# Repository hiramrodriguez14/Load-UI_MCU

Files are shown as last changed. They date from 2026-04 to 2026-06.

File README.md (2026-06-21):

# Horizontal Axis Wind Turbine Electronic Control Unit (ECU)

## Load Control & User Interface PCB

Printed Circuit Board (PCB) design for the **Load Control & User Interface (Load & UI) MCU** of the **Horizontal Axis Wind Turbine Electronic Control Unit (ECU)**.

This repository contains the complete KiCad hardware design, manufacturing files, and production documentation for the embedded controller responsible for battery charging, power management, user interaction, and system monitoring.

---

# Documentation & Demo

| Resource | Link |
| --- | --- |
| 🎥 Project Demonstration | https://www.youtube.com/watch?v=vS5Ok38P1Jk |
| 📄 Final Project Report | https://drive.google.com/file/d/1cckKhvj7mvzCEbm3IqWp0KvrUp9g6mgg/view?usp=sharing |
| 📚 Technical Appendix | https://drive.google.com/file/d/1xu7MtcffDlpna8_BUkwEc_BfjpQJpUep/view?usp=sharing |

---

# Overview

The Load Control & User Interface PCB serves as the primary electrical control board of the Horizontal Axis Wind Turbine Electronic Control Unit (ECU).

Designed using **KiCad**, this board integrates sensing, power management, user interaction, communication, and data logging into a single embedded platform. It operates alongside the Turbine MCU PCB to provide complete supervision of the wind turbine system.

The PCB was designed with debugging, manufacturability, and future expansion in mind, incorporating dedicated test points, modular circuitry, and production-ready manufacturing files.

---

# Engineering Highlights

- Custom 2-layer PCB
- Designed in KiCad
- Texas Instruments MSPM0G3519
- Dual INA229 Power Monitors
- SEPIC Converter Control
- Battery Management System (BMS)
- LCD User Interface
- Push Button Interface
- Status LEDs
- UART Communication
- microSD Card Interface
- Relay Driver
- Barrel Jack Power Input
- Production-ready Gerber files
- Pick-and-Place (CPL) files
- Manufacturing BOM

---

# Hardware Features

The PCB integrates the following subsystems:

### Power Management

- Battery charging controller
- SEPIC converter interface
- Power monitoring
- Relay control
- Load protection

### User Interface

- 20×4 LCD connector
- Navigation buttons
- Record button
- Start / Stop controls
- Status LEDs

### Communication

- UART interface to Turbine MCU
- Programming interface
- Debug connectors

### Data Logging

- microSD card socket
- Real-Time Clock (RTC)

---

# Hardware Architecture

The Load Control & UI PCB serves as the electrical management hub of the complete ECU.

Primary functions include:

- Battery charging
- Converter control
- Power measurement
- User interaction
- Data logging
- Load protection
- Communication with the Turbine MCU

<p align="center">
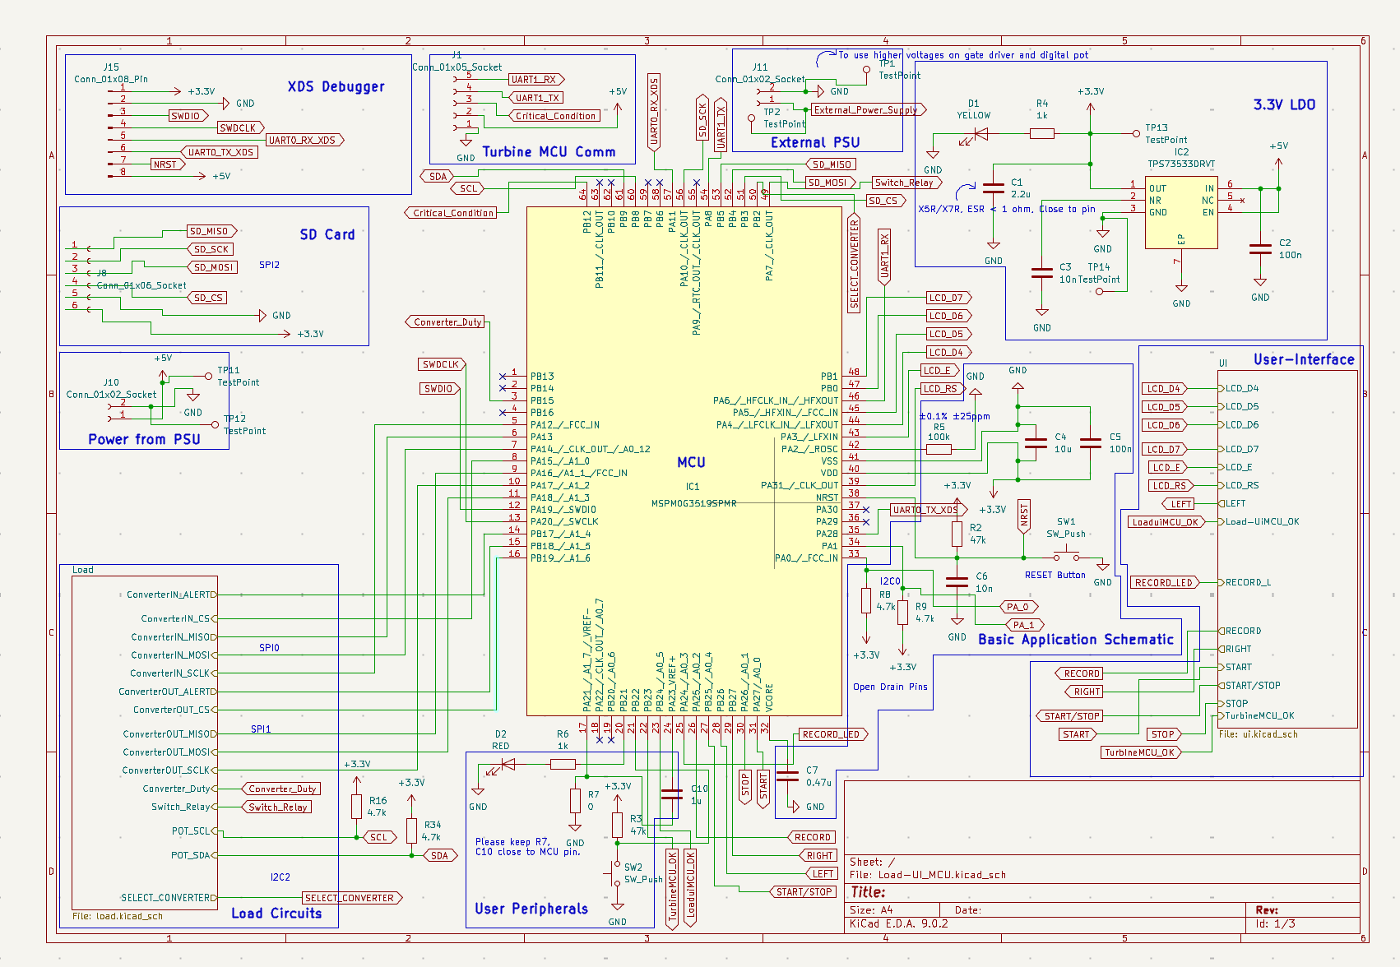
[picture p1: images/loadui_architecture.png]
  
</p>

<p align="center">
<b>Figure 1.</b> Load & UI MCU Architecture
</p>

---

# PCB Design

The board was designed using KiCad following standard PCB design practices for embedded systems.

Design considerations include:

- Component placement optimization
- Short signal routing
- Power integrity
- Ground plane utilization
- Test point accessibility
- Manufacturing compatibility

## Top Layer

<p align="center">
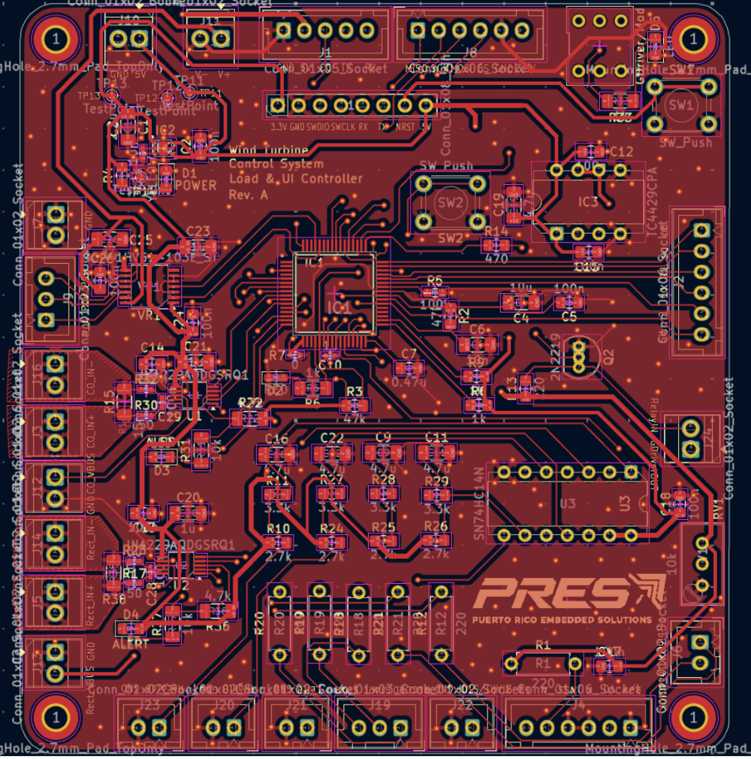
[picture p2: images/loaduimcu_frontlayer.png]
  
</p>

<p align="center">
<b>Figure 2.</b> Top Layer PCB Layout
</p>

---

## Bottom Layer

<p align="center">
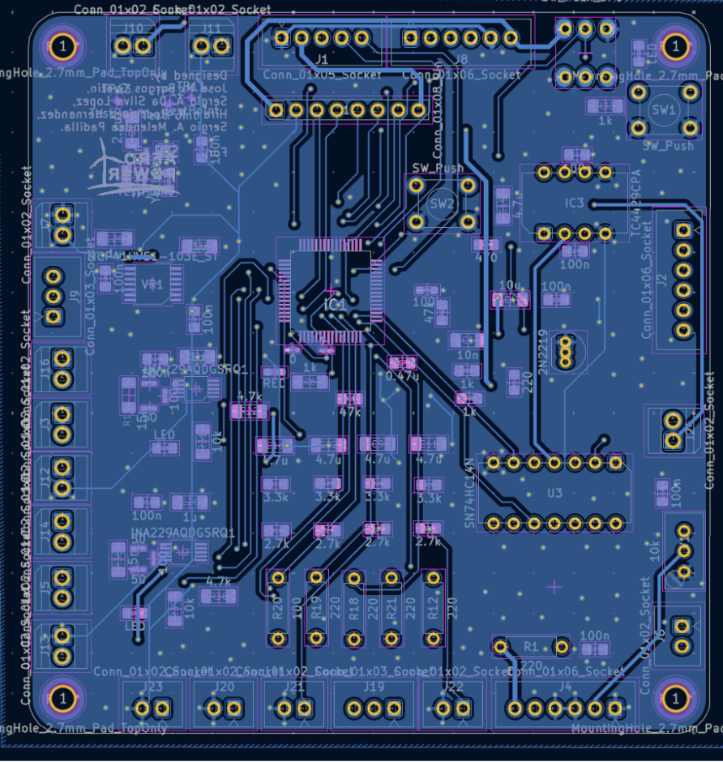
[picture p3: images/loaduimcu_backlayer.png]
  
</p>

<p align="center">
<b>Figure 3.</b> Bottom Layer PCB Layout
</p>

---

## Combined Layer View

<p align="center">
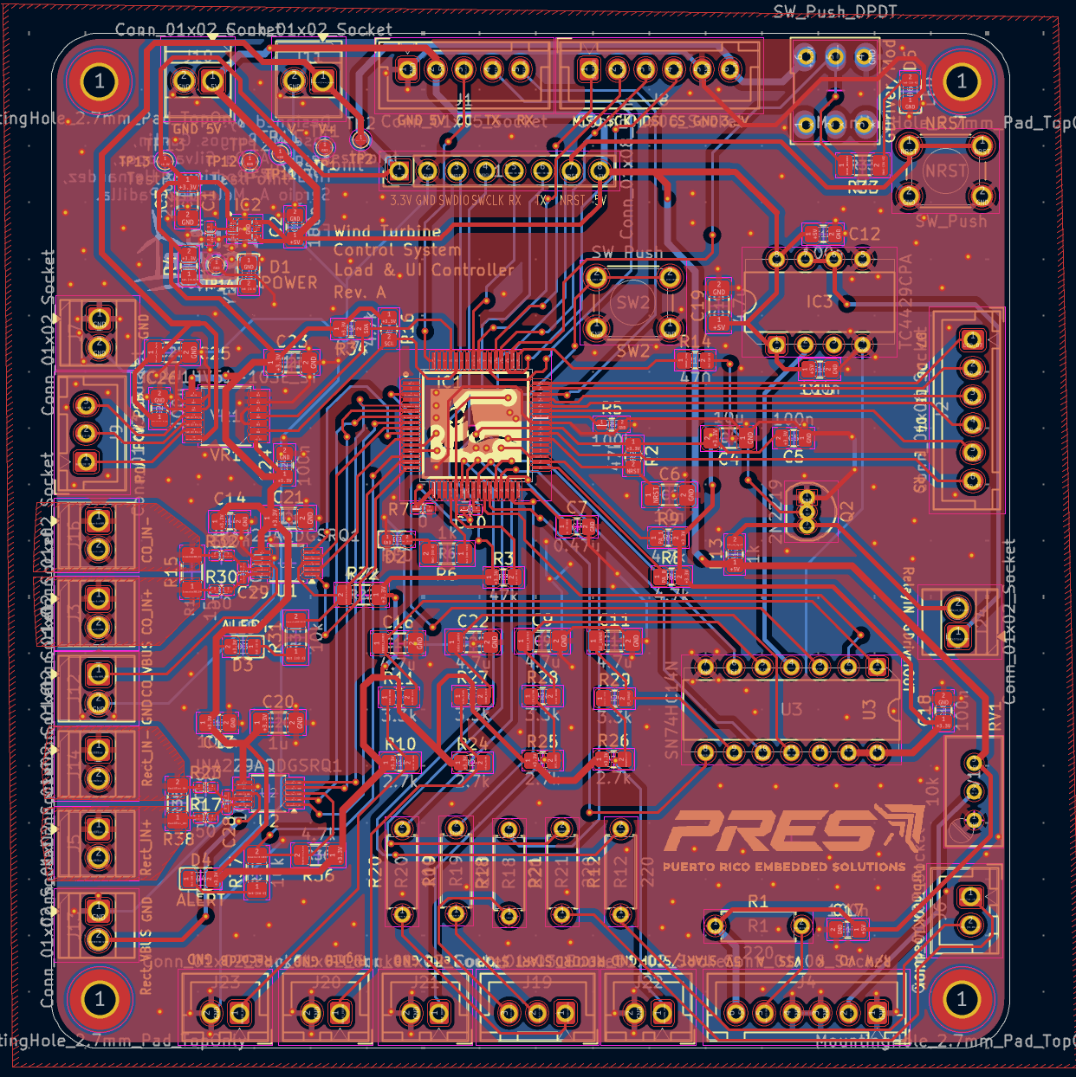
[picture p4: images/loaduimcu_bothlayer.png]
  
</p>

<p align="center">
<b>Figure 4.</b> Combined PCB Layers
</p>

---

## 3D PCB View

<p align="center">
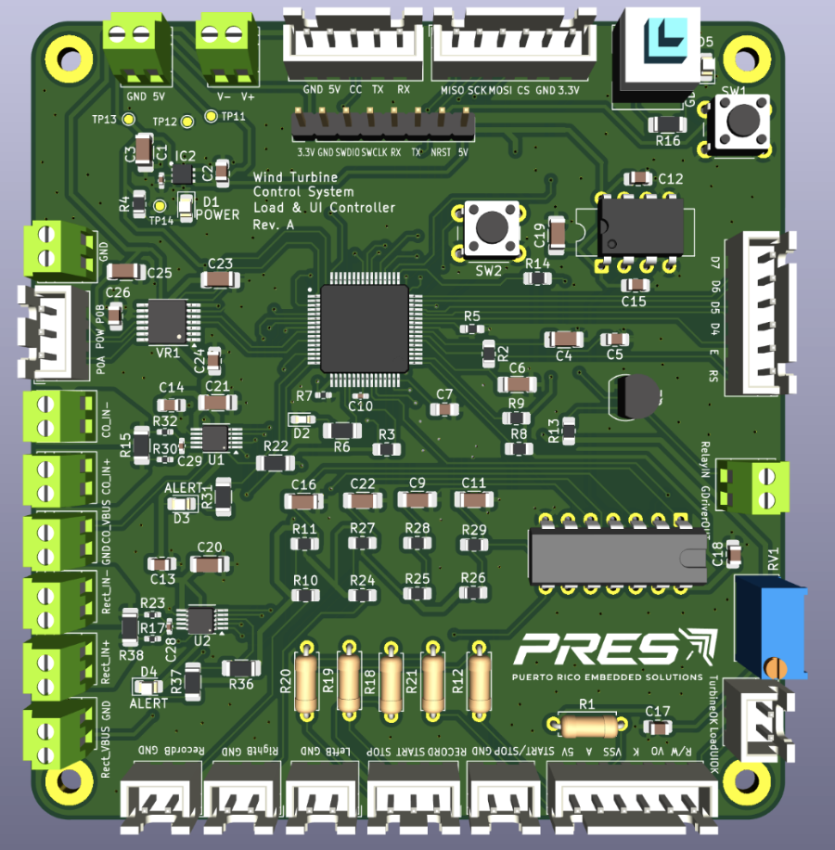
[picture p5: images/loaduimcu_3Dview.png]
  
</p>

<p align="center">
<b>Figure 5.</b> 3D PCB Rendering
</p>

---

# Manufacturing Files

This repository includes all files required for PCB fabrication and assembly.

Included manufacturing assets:

- Gerber files
- Drill files
- Pick-and-Place (CPL)
- Bill of Materials (BOM)
- Complete schematic
- PCB layout

---

# Development Tools

## PCB Design

- KiCad

## Target MCU

- Texas Instruments MSPM0G3519

---

# Repository Structure

```text
HAWT-LoadUI-PCB
│
├── gerbers/                    Manufacturing Gerber files
├── images/                     Documentation images
├── mylib/                      Custom KiCad component library
├── Load-UI_MCU.kicad_pcb       PCB layout
├── Load-UI_MCU.kicad_sch       Main schematic
├── Load-UI_MCU.kicad_pro       KiCad project
├── Load-UI_MCU-final.csv       Manufacturing BOM
├── Load-UI_MCU-all-pos.csv     Pick-and-Place (CPL)
├── load.kicad_sch              Power subsystem schematic
├── ui.kicad_sch                User Interface schematic
├── README.md                   Repository documentation
└── LICENSE                     Project license
```

---

# Related Repositories

| Repository | Description |
| --- | --- |
| HAWT-TurbineMCU-Firmware | Turbine control firmware |
| HAWT-Load_Control_and_UI | Load Control & UI firmware |
| Turbine_MCU | Turbine MCU PCB |

---

# Authors

- Hiram R. Rodríguez Hernández
- José M. Burgos Guntín
- Sergio A. Meléndez Padilla
- Sergio A. Da Silva López

Department of Electrical & Computer Engineering

University of Puerto Rico – Mayagüez

---

# License

This project was developed for educational and research purposes as part of the Embedded Systems Design course at the University of Puerto Rico – Mayagüez.

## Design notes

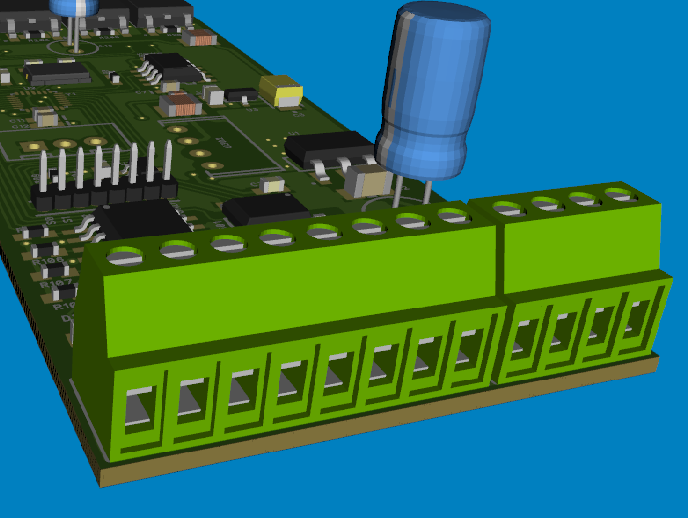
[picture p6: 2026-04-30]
mylib/kf128-screw-terminal-2-54-mm-pitch-1.snapshot.2/KF128-2.54-xx.png

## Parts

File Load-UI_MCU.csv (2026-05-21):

Designator | Qty | Comment | DNP | Exclude from BOM | Exclude from Board | Footprint | Datasheet | JLCPCB Part#
C1 | 1 | 2.2u |  |  |  | Capacitor_SMD:C_1206_3216Metric_Pad1.33x1.80mm_HandSolder | ~ | C50254
C2,C5,C12,C13,C14,C15,C17,C18,C24,C26 | 10 | 100n |  |  |  | Capacitor_SMD:C_0805_2012Metric_Pad1.18x1.45mm_HandSolder | ~ | C28233
C3 | 1 | 10n |  |  |  | Capacitor_SMD:C_0402_1005Metric_Pad0.74x0.62mm_HandSolder | ~ | C15195
C4 | 1 | 10u |  |  |  | Capacitor_SMD:C_1206_3216Metric_Pad1.33x1.80mm_HandSolder | ~ | C13585
C6 | 1 | 10n |  |  |  | Capacitor_SMD:C_1206_3216Metric_Pad1.33x1.80mm_HandSolder | ~ | C1846
C7 | 1 | 0.47u |  |  |  | Capacitor_SMD:C_0805_2012Metric_Pad1.18x1.45mm_HandSolder | ~ | C13967
C9,C11,C16,C19,C22 | 5 | 4.7u |  |  |  | Capacitor_SMD:C_1206_3216Metric_Pad1.33x1.80mm_HandSolder | ~ | C29823
C10 | 1 | 1u |  |  |  | Capacitor_SMD:C_0402_1005Metric_Pad0.74x0.62mm_HandSolder | ~ | C52923
C20,C21,C23,C25 | 4 | 1u |  |  |  | Capacitor_SMD:C_1206_3216Metric_Pad1.33x1.80mm_HandSolder | ~ | C1848
C28,C29 | 2 | 100n |  |  |  | Capacitor_SMD:C_0402_1005Metric_Pad0.74x0.62mm_HandSolder | ~ | C307331
D1 | 1 | YELLOW |  |  |  | LED_SMD:LED_0805_2012Metric_Pad1.15x1.40mm_HandSolder | ~ | C2296
D2 | 1 | RED |  |  |  | LED_SMD:LED_0603_1608Metric_Pad1.05x0.95mm_HandSolder | ~ | C2286
D3,D4,D6 | 3 | LED |  |  |  | LED_SMD:LED_0805_2012Metric_Pad1.15x1.40mm_HandSolder | ~ | C2296
IC1 | 1 | MSPM0G3519SPMR |  |  |  | MSPM0SPMR:QFP50P1200X1200X160-64N | https://www.ti.com/lit/ds/symlink/mspm0g3505.pdf?ts=1706855132968 | C49259417
IC2 | 1 | TPS73533DRVT |  |  |  | TPS73533DRVT:SON65P200X200X80-7N | http://www.ti.com/lit/ds/symlink/tps735.pdf | C48984
IC3 | 1 | TC4429CPA |  |  | YES | Package_DIP:CERDIP-8_W7.62mm_SideBrazed | https://ww1.microchip.com/downloads/en/DeviceDoc/21419D.pdf
J1 | 1 | Conn_01x05_Socket |  |  | YES | Connector_JST:JST_XH_B5B-XH-A_1x05_P2.50mm_Vertical | ~
J2,J4,J8 | 3 | Conn_01x06_Socket |  |  | YES | Connector_JST:JST_XH_B6B-XH-A_1x06_P2.50mm_Vertical | ~
J3,J5,J7,J10,J11,J12,J13,J14,J16,J24 | 10 | Conn_01x02_Socket |  |  | YES | TerminalBlock:TerminalBlock_Xinya_XY308-2.54-2P_1x02_P2.54mm_Horizontal | ~
J6,J20,J21,J22,J23 | 5 | Conn_01x02_Socket |  |  | YES | Connector_JST:JST_XH_B2B-XH-A_1x02_P2.50mm_Vertical | ~
J9,J19 | 2 | Conn_01x03_Socket |  |  | YES | Connector_JST:JST_XH_B3B-XH-A_1x03_P2.50mm_Vertical | ~
J15 | 1 | Conn_01x08_Pin |  |  | YES | Connector_PinHeader_2.54mm:PinHeader_1x08_P2.54mm_Vertical | ~
Q2 | 1 | 2N2219 |  |  | YES | Package_TO_SOT_THT:TO-92_Inline | http://www.onsemi.com/pub_link/Collateral/2N2219-D.PDF
R1,R12,R18,R19,R21 | 5 | 220 |  |  | YES | Resistor_THT:R_Axial_DIN0207_L6.3mm_D2.5mm_P7.62mm_Horizontal | ~
R2,R3 | 2 | 47k |  |  |  | Resistor_SMD:R_0805_2012Metric_Pad1.20x1.40mm_HandSolder | ~ | C17713
R4,R13 | 2 | 1k |  |  |  | Resistor_SMD:R_0805_2012Metric_Pad1.20x1.40mm_HandSolder | ~ | C17513
R5 | 1 | 100k |  |  |  | Resistor_SMD:R_0603_1608Metric_Pad0.98x0.95mm_HandSolder | ~ | C25803
R6,R33 | 2 | 1k |  |  |  | Resistor_SMD:R_1206_3216Metric_Pad1.30x1.75mm_HandSolder | ~ | C4410
R7 | 1 | 0R |  |  |  | Resistor_SMD:R_0402_1005Metric_Pad0.72x0.64mm_HandSolder | ~ | C17168
R8,R9,R16,R34 | 4 | 4.7k |  |  |  | Resistor_SMD:R_0805_2012Metric_Pad1.20x1.40mm_HandSolder | ~ | C17675
R10,R24,R25,R26 | 4 | 2.7k |  |  |  | Resistor_SMD:R_0805_2012Metric_Pad1.20x1.40mm_HandSolder | ~ | C17530
R11,R27,R28,R29 | 4 | 3.3k |  |  |  | Resistor_SMD:R_0805_2012Metric_Pad1.20x1.40mm_HandSolder | ~ | C26010
R14 | 1 | 470 |  |  |  | Resistor_SMD:R_0805_2012Metric_Pad1.20x1.40mm_HandSolder | ~ | C17710
R15,R38 | 2 | 15m |  |  |  | Resistor_SMD:R_1206_3216Metric_Pad1.30x1.75mm_HandSolder | ~ | C601098
R17,R23,R30,R32 | 4 | 50 |  |  |  | Resistor_SMD:R_0402_1005Metric_Pad0.72x0.64mm_HandSolder | ~ | C25120
R20 | 1 | 100 |  |  | YES | Resistor_THT:R_Axial_DIN0207_L6.3mm_D2.5mm_P7.62mm_Horizontal | ~
R22,R36 | 2 | 4.7k |  |  |  | Resistor_SMD:R_1206_3216Metric_Pad1.30x1.75mm_HandSolder | ~ | C17936
R31,R37 | 2 | 10k |  |  |  | Resistor_SMD:R_1206_3216Metric_Pad1.30x1.75mm_HandSolder | ~ | C17902
RV1 | 1 | 10k |  |  | YES | Potentiometer_THT:Potentiometer_Bourns_3296W_Vertical | ~
SW1,SW2 | 2 | SW_Push |  |  | YES | Button_Switch_THT:SW_PUSH_6mm | ~
SW4 | 1 | SW_Push_DPDT |  |  | YES | Latch_PB:SW_DPDT_XLX | ~
TP1,TP2,TP11,TP12,TP13,TP14 | 6 | TestPoint |  |  | YES | TestPoint:TestPoint_Pad_D1.0mm | ~
U1,U2 | 2 | INA229AQDGSRQ1 |  |  |  | Package_SO:VSSOP-10_3x3mm_P0.5mm | https://www.ti.com/lit/gpn/ina229-q1 | C2846803
U3 | 1 | SN74HC14N |  |  | YES | Package_DIP:CERDIP-14_W7.62mm_SideBrazed | http://www.ti.com/lit/gpn/sn74LS14
VR1 | 1 | MCP41HV51-103E_ST |  |  | YES | Package_SO:TSSOP-14_4.4x5mm_P0.65mm | https://componentsearchengine.com/Datasheets/2/MCP41HV51-103E_ST.pdf

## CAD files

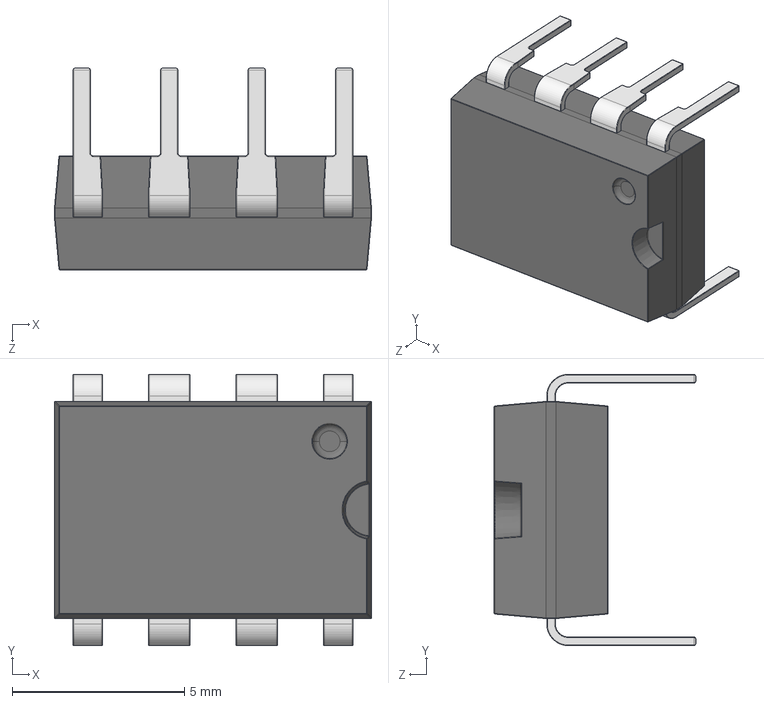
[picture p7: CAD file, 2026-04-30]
mylib/DIP8.STEP
9.20 x 7.87 x 5.85 mm

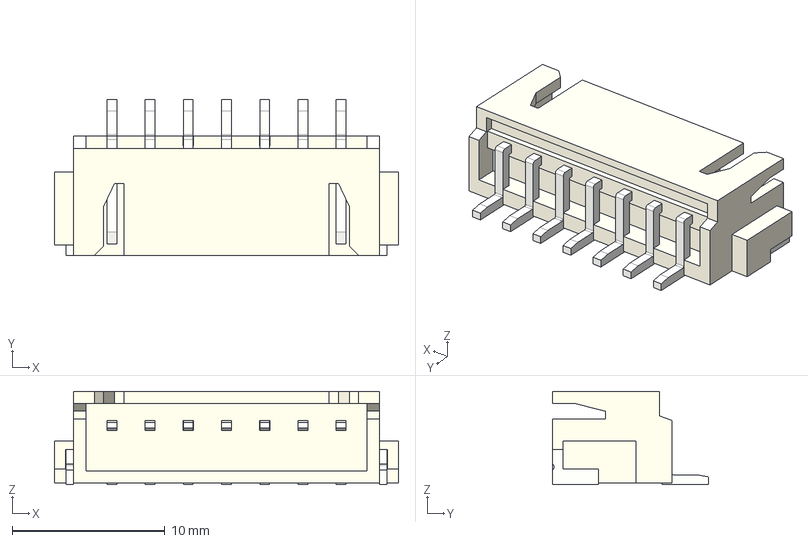
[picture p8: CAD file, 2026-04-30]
mylib/JST_3D/JST-XH7-SMD.step
22.5 x 10.2 x 6.10 mm

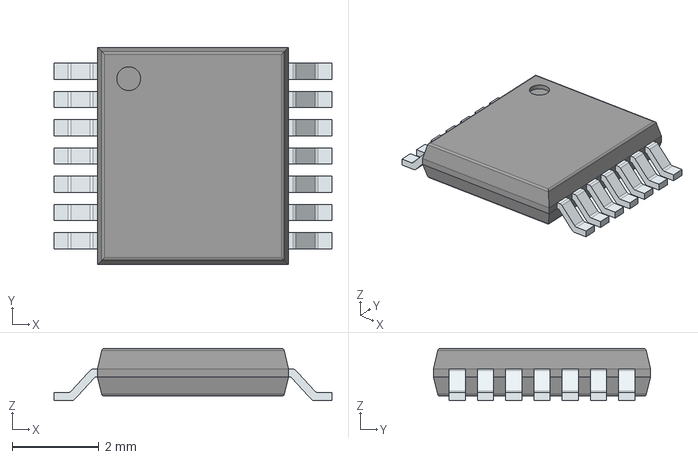
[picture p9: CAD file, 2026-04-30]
mylib/LIB_MCP41HV51-103E_ST/MCP41HV51-103E_ST/3D/MCP41HV51-103E_ST.stp
6.40 x 5.00 x 1.20 mm
PinsArrayLR

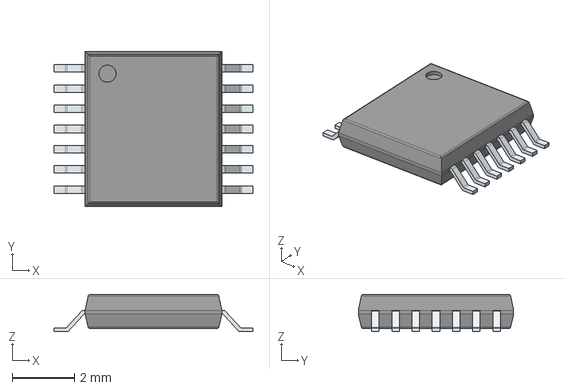
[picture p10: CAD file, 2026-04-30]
mylib/LIB_MCP45HV51-103E_ST/MCP45HV51-103E_ST/3D/MCP45HV51-103E_ST.stp
6.40 x 5.00 x 1.20 mm
PinsArrayLR

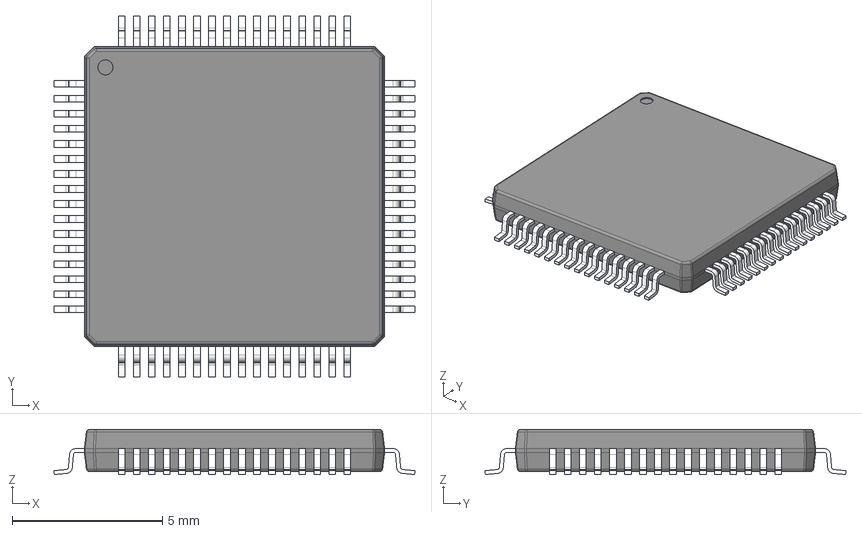
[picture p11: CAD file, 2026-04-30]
mylib/LIB_MSPM0G3507SPMR/MSPM0G3507SPMR/3D/MSPM0G3507SPMR.stp
12.0 x 12.0 x 1.50 mm
BODY-QFP
LEAD-QFP x 64

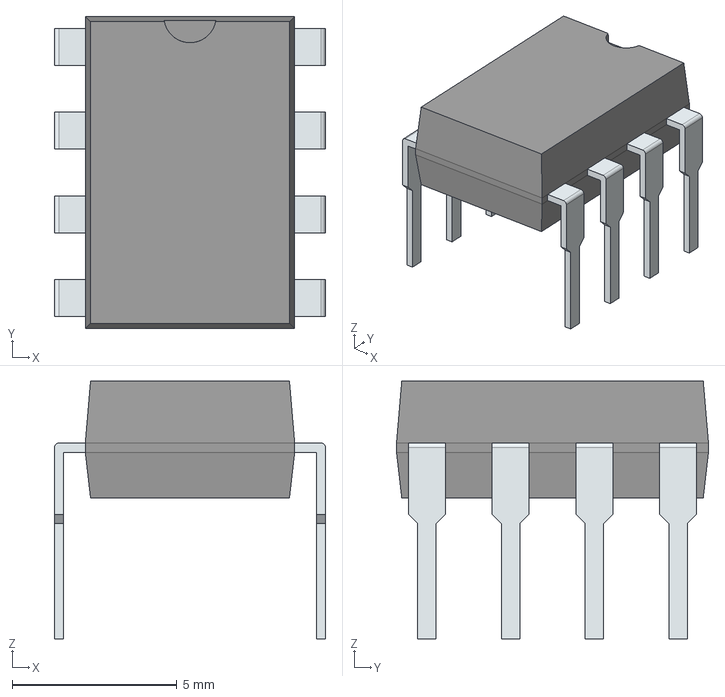
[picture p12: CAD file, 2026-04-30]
mylib/LIB_TC4429CPA/TC4429CPA/3D/TC4429CPA.stp
8.22 x 9.46 x 7.82 mm
PinsArrayLR

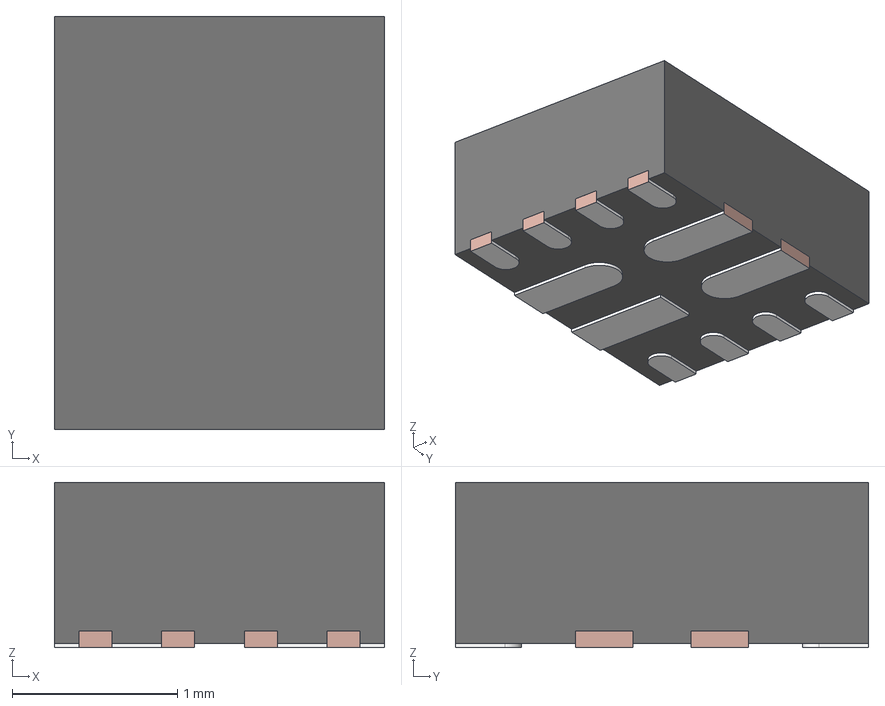
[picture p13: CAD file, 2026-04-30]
mylib/LIB_TPS2121RUXR/TPS2121RUXR/3D/TPS2121RUXR.stp
2.00 x 2.50 x 1.00 mm
FRAME
MOLD

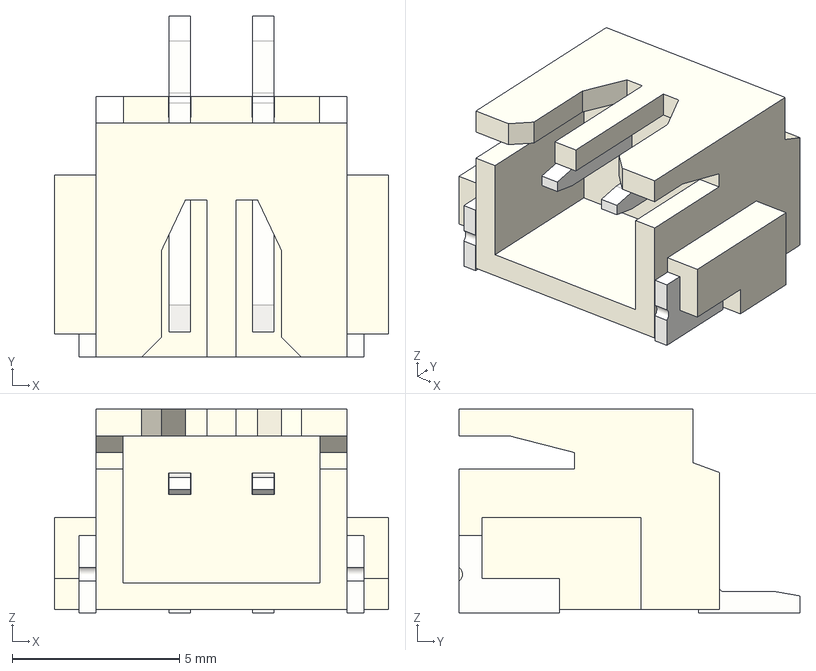
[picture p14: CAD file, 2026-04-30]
mylib/JST_3D/JST-XH2-SMD.step
10.0 x 10.2 x 6.10 mm

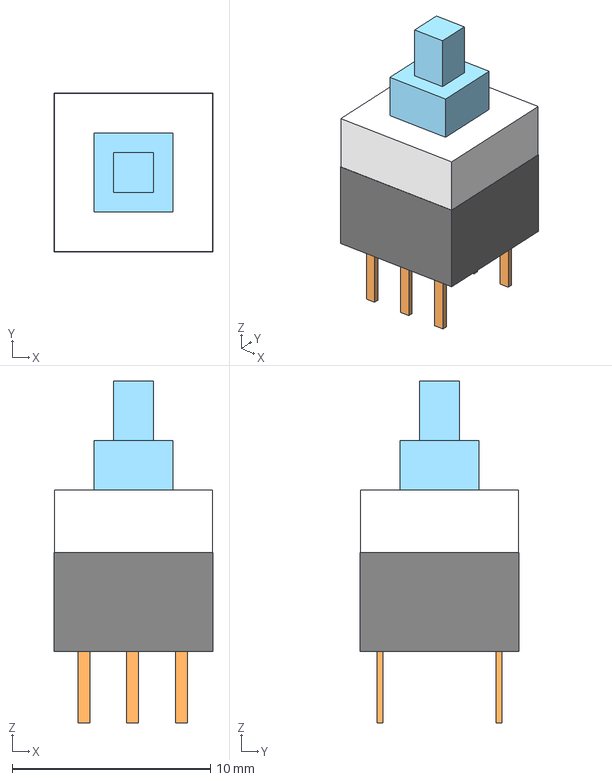
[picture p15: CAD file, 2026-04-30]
mylib/SW_Btn_XLX.step
8.00 x 8.00 x 17.2 mm

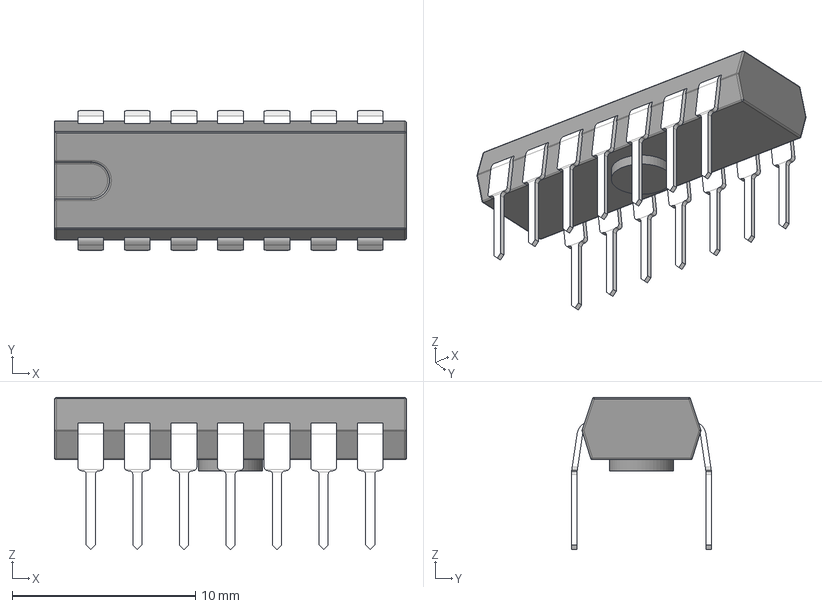
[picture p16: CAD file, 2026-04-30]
mylib/DIL14.stp
19.2 x 7.62 x 8.30 mm
DIP14_body
legs x 7

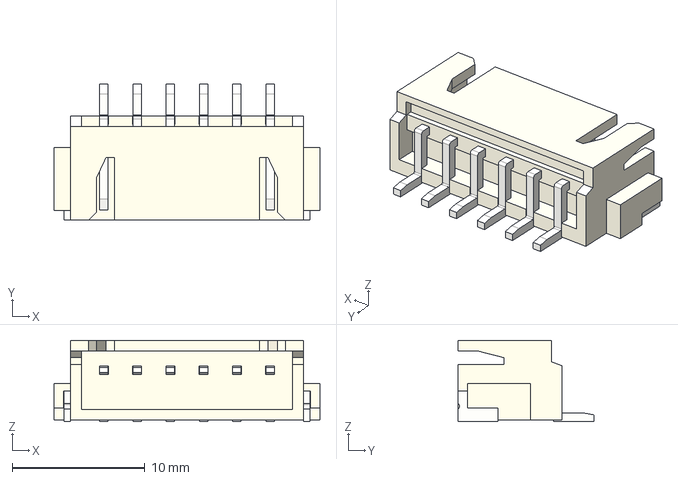
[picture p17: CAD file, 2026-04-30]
mylib/JST_3D/JST-XH6-SMD.step
20.0 x 10.2 x 6.10 mm

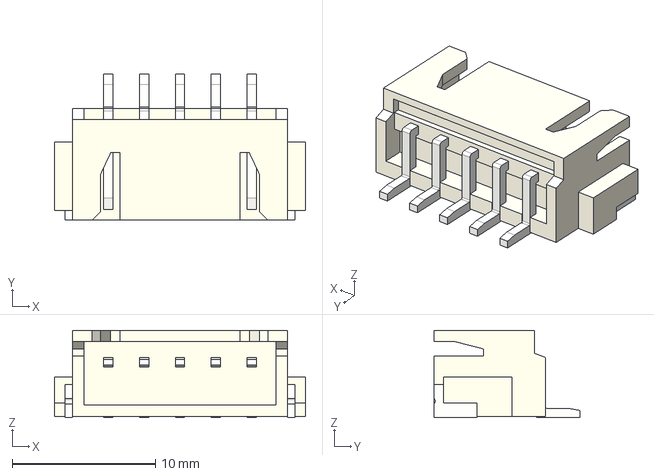
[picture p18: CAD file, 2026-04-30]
mylib/JST_3D/JST-XH5-SMD.step
17.5 x 10.2 x 6.10 mm

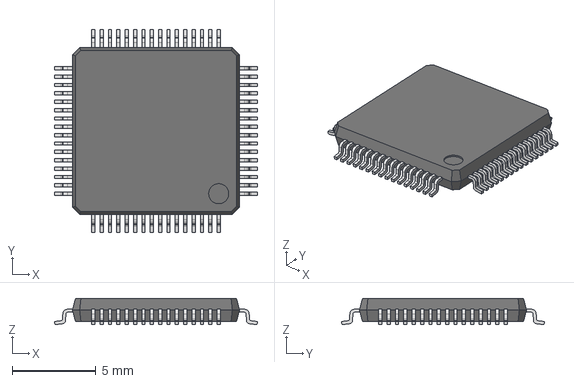
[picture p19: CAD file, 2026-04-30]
mylib/LQFP64 v1.step
12.1 x 12.1 x 1.58 mm

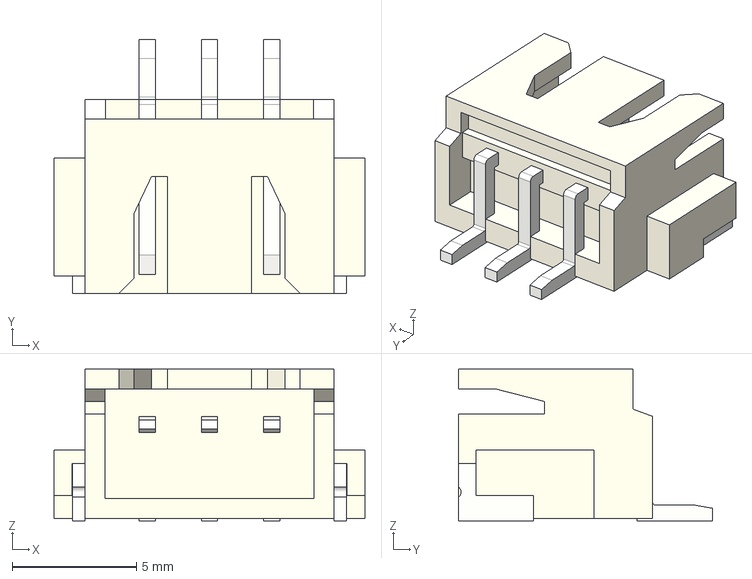
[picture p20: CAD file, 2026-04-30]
mylib/JST_3D/JST-XH3-SMD.step
12.5 x 10.2 x 6.10 mm

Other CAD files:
mylib/WSON-6_2x2.step
mylib/JST_3D/JST-XH4-SMD.step
mylib/kf128-screw-terminal-2-54-mm-pitch-1.snapshot.2/KF128 2.54mm/KF128-2.54-9P.step
mylib/LIB_TPS61046YFFR/TPS61046YFFR/3D/TPS61046YFFR.stp
mylib/LIB_MCP41HV51-103E_ST/MCP41HV51-103E_ST/Allegro/sop65p640x120-14n.psm
mylib/LIB_MCP41HV51-103E_ST/MCP41HV51-103E_ST/DEHDL/mcp41hv51_103e_st/chips/chips.prt
mylib/LIB_MCP45HV51-103E_ST/MCP45HV51-103E_ST/Allegro/sop65p640x120-14n.psm
mylib/LIB_MCP45HV51-103E_ST/MCP45HV51-103E_ST/DEHDL/mcp45hv51_103e_st/chips/chips.prt
mylib/LIB_MSPM0G3507SPMR/MSPM0G3507SPMR/Allegro/qfp50p1200x1200x160-64n.psm
mylib/LIB_MSPM0G3507SPMR/MSPM0G3507SPMR/DEHDL/mspm0g3507spmr/chips/chips.prt
mylib/LIB_TC4429CPA/TC4429CPA/Allegro/dip794w56p254l946h432q8n.psm
mylib/LIB_TC4429CPA/TC4429CPA/DEHDL/tc4429cpa/chips/chips.prt
mylib/LIB_TPS2121RUXR/TPS2121RUXR/Allegro/tps2121ruxr.psm
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

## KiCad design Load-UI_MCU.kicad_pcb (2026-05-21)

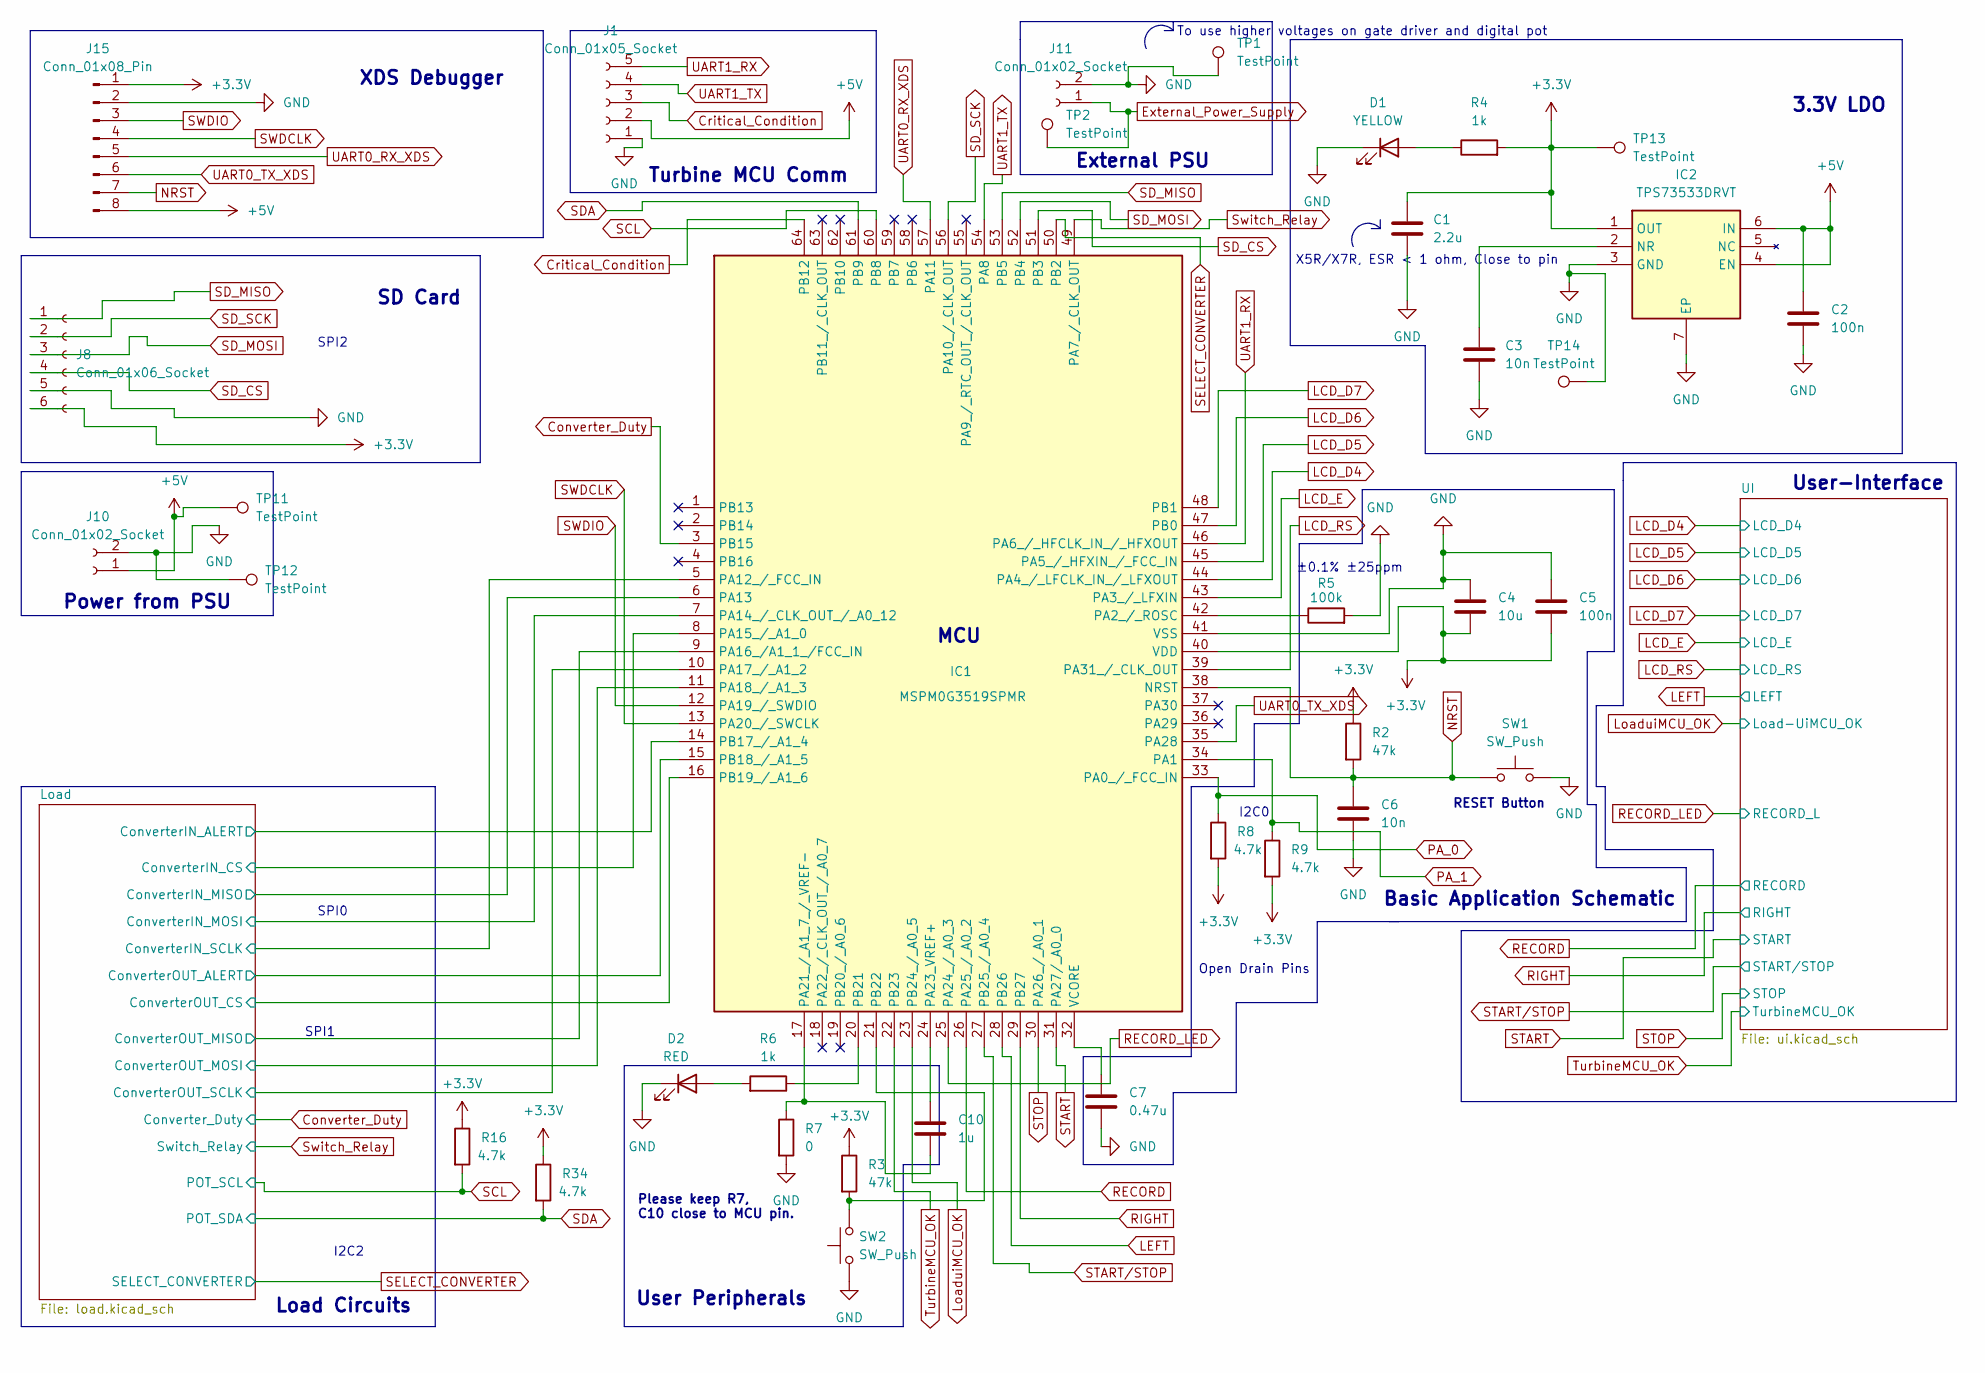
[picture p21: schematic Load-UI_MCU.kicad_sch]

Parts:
C1: 2.2u; C_1206_3216Metric_Pad1.33x1.80mm_HandSolder
C2, C5: 100n; C_0805_2012Metric_Pad1.18x1.45mm_HandSolder
C3: 10n; C_0402_1005Metric_Pad0.74x0.62mm_HandSolder
C4: 10u; C_1206_3216Metric_Pad1.33x1.80mm_HandSolder
C6: 10n; C_1206_3216Metric_Pad1.33x1.80mm_HandSolder
C7: 0.47u; C_0805_2012Metric_Pad1.18x1.45mm_HandSolder
C10: 1u; C_0402_1005Metric_Pad0.74x0.62mm_HandSolder
D1: YELLOW; LED_0805_2012Metric_Pad1.15x1.40mm_HandSolder
D2: RED; LED_0603_1608Metric_Pad1.05x0.95mm_HandSolder
IC1: MSPM0G3519SPMR; QFP50P1200X1200X160-64N; Mouser Part Number 595-MSPM0G3507SPMR
IC2: TPS73533DRVT; SON65P200X200X80-7N; Mouser Part Number 595-TPS73533DRVT
J1: Conn_01x05_Socket; JST_XH_B5B-XH-A_1x05_P2.50mm_Vertical
J8: Conn_01x06_Socket; JST_XH_B6B-XH-A_1x06_P2.50mm_Vertical
J10, J11: Conn_01x02_Socket; TerminalBlock_Xinya_XY308-2.54-2P_1x02_P2.54mm_Horizontal
J15: Conn_01x08_Pin; PinHeader_1x08_P2.54mm_Vertical
R2, R3: 47k; R_0805_2012Metric_Pad1.20x1.40mm_HandSolder
R4: 1k; R_0805_2012Metric_Pad1.20x1.40mm_HandSolder
R5: 100k; R_0603_1608Metric_Pad0.98x0.95mm_HandSolder
R6: 1k; R_1206_3216Metric_Pad1.30x1.75mm_HandSolder
R7: 0; R_0402_1005Metric_Pad0.72x0.64mm_HandSolder
R8, R9, R16, R34: 4.7k; R_0805_2012Metric_Pad1.20x1.40mm_HandSolder
SW1, SW2: SW_Push; SW_PUSH_6mm
TP1, TP2, TP11, TP12, TP13, TP14: TestPoint; TestPoint_Pad_D1.0mm

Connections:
+3.3V: C1.1, C4.2, C5.2, IC1.40 (VDD), IC2.1 (OUT), J8.6, J15.1, R2.1, R3.1, R4.2, R8.2, R9.2, R16.1, R34.1, TP13.1; also elsewhere on the board
+5V: C2.1, IC2.4 (EN), IC2.6 (IN), J1.2, J10.1, J15.8, TP11.1; also elsewhere on the board
/Load/ConverterIN_ALERT: IC1.14 (PB17_/_A1_4); also elsewhere on the board
/Load/ConverterIN_CS: IC1.8 (PA15_/_A1_0); also elsewhere on the board
/Load/ConverterIN_MISO: IC1.6 (PA13); also elsewhere on the board
/Load/ConverterIN_MOSI: IC1.7 (PA14_/_CLK_OUT_/_A0_12); also elsewhere on the board
/Load/ConverterIN_SCLK: IC1.5 (PA12_/_FCC_IN); also elsewhere on the board
/Load/ConverterOUT_ALERT: IC1.15 (PB18_/_A1_5); also elsewhere on the board
/Load/ConverterOUT_CS: IC1.16 (PB19_/_A1_6); also elsewhere on the board
/Load/ConverterOUT_MISO: IC1.9 (PA16_/A1_1_/FCC_IN); also elsewhere on the board
/Load/ConverterOUT_MOSI: IC1.11 (PA18_/_A1_3); also elsewhere on the board
/Load/ConverterOUT_SCLK: IC1.10 (PA17_/_A1_2); also elsewhere on the board
Converter_Duty: IC1.3 (PB15); also elsewhere on the board
Critical_Condition: IC1.64 (PB12), J1.3
External_Power_Supply: J11.1, TP2.1; also elsewhere on the board
GND: C1.2, C2.2, C3.2, C4.1, C5.1, C6.2, C7.2, D1.1 (K), D2.1 (K), IC1.41 (VSS), IC2.3 (GND), IC2.7 (EP), J1.1, J8.5, J10.2, J11.2, J15.2, R5.2, R7.2, SW1.2, SW2.1, TP1.1, TP12.1, TP14.1; also elsewhere on the board
LCD_D4: IC1.44 (PA4_/_LFCLK_IN_/_LFXOUT); also elsewhere on the board
LCD_D5: IC1.45 (PA5_/_HFXIN_/_FCC_IN); also elsewhere on the board
LCD_D6: IC1.47 (PB0); also elsewhere on the board
LCD_D7: IC1.48 (PB1); also elsewhere on the board
LCD_E: IC1.43 (PA3_/_LFXIN); also elsewhere on the board
LCD_RS: IC1.39 (PA31_/_CLK_OUT); also elsewhere on the board
LEFT: IC1.28 (PB26); also elsewhere on the board
LoaduiMCU_OK: IC1.23 (PB24_/_A0_5); also elsewhere on the board
NRST: C6.1, IC1.38 (NRST), J15.7, R2.2, SW1.1; also elsewhere on the board
unnamed: D1.2 (A), R4.1
unnamed: D2.2 (A), R6.2
unnamed: IC1.42 (PA2_/_ROSC), R5.1
unnamed: C10.2, IC1.17 (PA21_/_A1_7_/_VREF-), R7.1
unnamed: C10.1, IC1.24 (PA23_VREF+)
unnamed: IC1.20 (PB21), R6.1
unnamed: IC1.21 (PB22), R3.2, SW2.2
unnamed: C7.1, IC1.32 (VCORE)
unnamed: C3.1, IC2.2 (NR)
PA_0: IC1.33 (PA0_/_FCC_IN), R8.1
PA_1: IC1.34 (PA1), R9.1
POT_CS: IC1.1 (PB13)
RECORD: IC1.26 (PA25_/_A0_2); also elsewhere on the board
RECORD_LED: IC1.25 (PA24_/_A0_3); also elsewhere on the board
RIGHT: IC1.29 (PB27); also elsewhere on the board
SCL: IC1.60 (PB8), R16.2; also elsewhere on the board
SDA: IC1.61 (PB9), R34.2; also elsewhere on the board
SD_CS: IC1.51 (PB3), J8.4
SD_MISO: IC1.53 (PB5), J8.1
SD_MOSI: IC1.52 (PB4), J8.3
SD_SCK: IC1.56 (PA10_/_CLK_OUT), J8.2
SELECT_CONVERTER: IC1.50 (PB2); also elsewhere on the board
START: IC1.31 (PA27/_A0_0); also elsewhere on the board
START/STOP: IC1.27 (PB25_/_A0_4); also elsewhere on the board
STOP: IC1.30 (PA26_/_A0_1); also elsewhere on the board
SWDCLK: IC1.13 (PA20_/_SWCLK), J15.4
SWDIO: IC1.12 (PA19_/_SWDIO), J15.3
Switch_Relay: IC1.49 (PA7_/_CLK_OUT); also elsewhere on the board
TurbineMCU_OK: IC1.22 (PB23); also elsewhere on the board
UART0_RX_XDS: IC1.57 (PA11), J15.5
UART0_TX_XDS: IC1.35 (PA28), J15.6
UART1_RX: IC1.46 (PA6_/_HFCLK_IN_/_HFXOUT), J1.5
UART1_TX: IC1.54 (PA8), J1.4

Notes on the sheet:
To use higher voltages on gate driver and digital pot
SPI1
User Peripherals
MCU
SPI2
Basic Application Schematic
Load Circuits
RESET Button
User-Interface
Power from PSU
±0.1% ±25ppm
I2C0
SPI0
SD Card
External PSU
XDS Debugger
Please keep R7, C10 close to MCU pin.
3.3V LDO
I2C2
Open Drain Pins
X5R/X7R, ESR < 1 ohm, Close to pin
Turbine MCU Comm

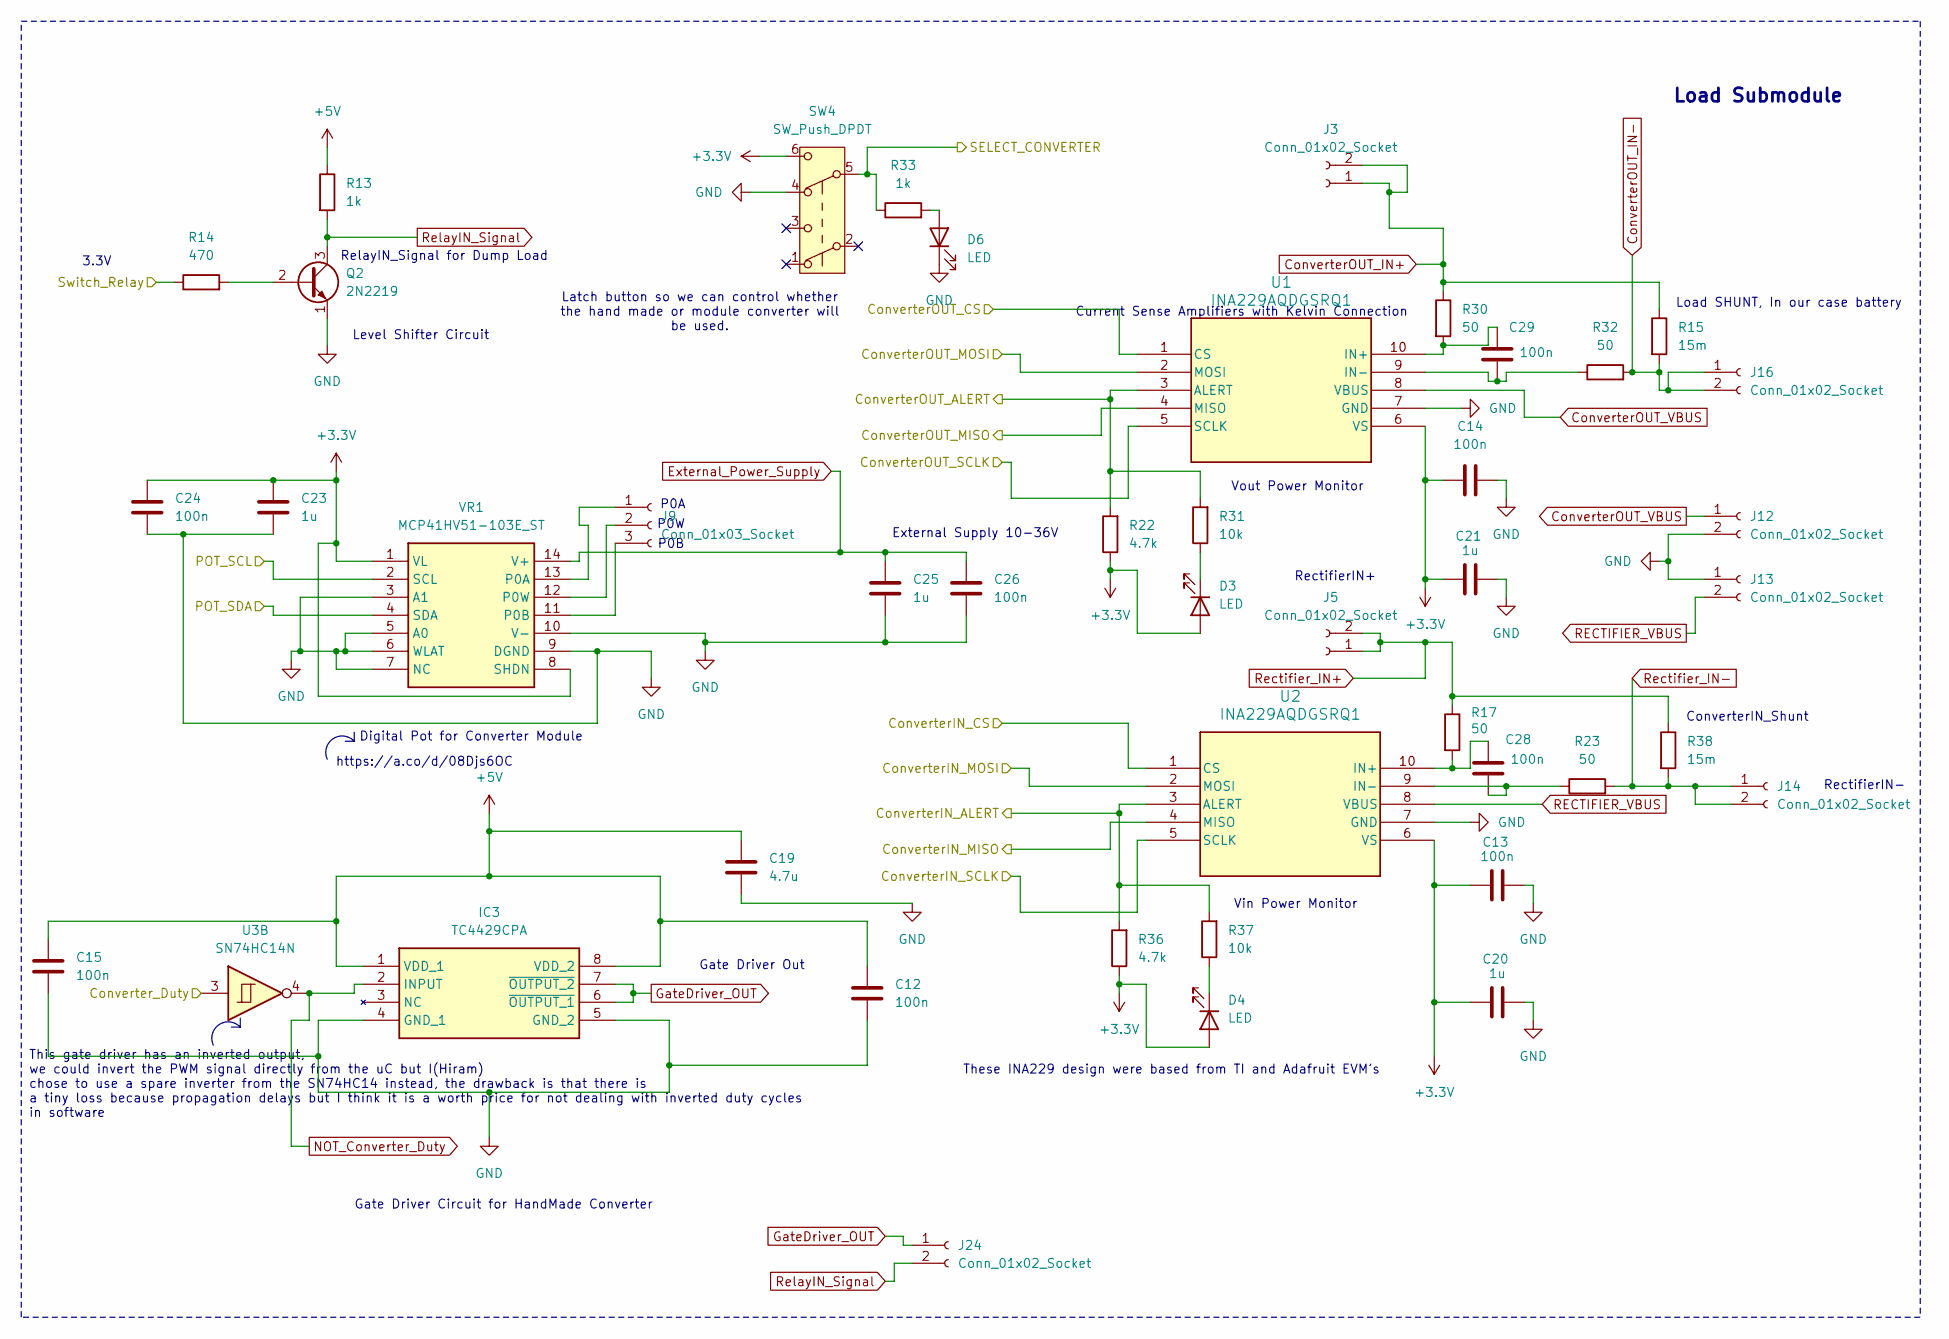
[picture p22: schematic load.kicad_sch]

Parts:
C12, C13, C14, C15, C24, C26: 100n; C_0805_2012Metric_Pad1.18x1.45mm_HandSolder
C19: 4.7u; C_1206_3216Metric_Pad1.33x1.80mm_HandSolder
C20, C21, C23, C25: 1u; C_1206_3216Metric_Pad1.33x1.80mm_HandSolder
C28, C29: 100n; C_0402_1005Metric_Pad0.74x0.62mm_HandSolder
D3, D4, D6: LED; LED_0805_2012Metric_Pad1.15x1.40mm_HandSolder
IC3: TC4429CPA; CERDIP-8_W7.62mm_SideBrazed; Mouser Part Number 579-TC4429CPA
J3, J5, J12, J13, J14, J16, J24: Conn_01x02_Socket; TerminalBlock_Xinya_XY308-2.54-2P_1x02_P2.54mm_Horizontal
J9: Conn_01x03_Socket; JST_XH_B3B-XH-A_1x03_P2.50mm_Vertical
Q2: 2N2219; TO-92_Inline
R13: 1k; R_0805_2012Metric_Pad1.20x1.40mm_HandSolder
R14: 470; R_0805_2012Metric_Pad1.20x1.40mm_HandSolder
R15, R38: 15m; R_1206_3216Metric_Pad1.30x1.75mm_HandSolder
R17, R23, R30, R32: 50; R_0402_1005Metric_Pad0.72x0.64mm_HandSolder
R22, R36: 4.7k; R_1206_3216Metric_Pad1.30x1.75mm_HandSolder
R31, R37: 10k; R_1206_3216Metric_Pad1.30x1.75mm_HandSolder
R33: 1k; R_1206_3216Metric_Pad1.30x1.75mm_HandSolder
SW4: SW_Push_DPDT; SW_DPDT_XLX
U1, U2: INA229AQDGSRQ1; VSSOP-10_3x3mm_P0.5mm
U3: SN74HC14N; CERDIP-14_W7.62mm_SideBrazed
VR1: MCP41HV51-103E_ST; TSSOP-14_4.4x5mm_P0.65mm; Mouser Part Number 579-MCP41HV51-103EST

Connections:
+3.3V: C13.1, C14.1, C20.1, C21.1, C23.1, C24.1, D3.2 (A), D4.2 (A), R22.1, R36.1, SW4.6 (C), U1.6 (VS), U2.6 (VS), VR1.1 (VL), VR1.8 (SHDN); also elsewhere on the board
+5V: C12.1, C15.1, C19.1, IC3.1 (VDD_1), IC3.8 (VDD_2), R13.1; also elsewhere on the board
/Load/ConverterIN_ALERT: R36.2, R37.2, U2.3 (ALERT); also elsewhere on the board
/Load/ConverterIN_CS: U2.1 (CS); also elsewhere on the board
/Load/ConverterIN_MISO: U2.4 (MISO); also elsewhere on the board
/Load/ConverterIN_MOSI: U2.2 (MOSI); also elsewhere on the board
/Load/ConverterIN_SCLK: U2.5 (SCLK); also elsewhere on the board
/Load/ConverterOUT_ALERT: R22.2, R31.2, U1.3 (ALERT); also elsewhere on the board
/Load/ConverterOUT_CS: U1.1 (CS); also elsewhere on the board
/Load/ConverterOUT_MISO: U1.4 (MISO); also elsewhere on the board
/Load/ConverterOUT_MOSI: U1.2 (MOSI); also elsewhere on the board
/Load/ConverterOUT_SCLK: U1.5 (SCLK); also elsewhere on the board
ConverterOUT_IN+: J3.1, J3.2, R15.1, R30.1
ConverterOUT_IN-: J16.1, J16.2, R15.2, R32.2
ConverterOUT_VBUS: J12.1, U1.8 (VBUS)
Converter_Duty: U3.3; also elsewhere on the board
External_Power_Supply: C25.1, C26.1, VR1.14 (V+); also elsewhere on the board
GND: C12.2, C13.2, C14.2, C15.2, C19.2, C20.2, C21.2, C23.2, C24.2, C25.2, C26.2, D6.1 (K), IC3.4 (GND_1), IC3.5 (GND_2), J12.2, J13.1, Q2.1 (E), SW4.4 (A), U1.7 (GND), U2.7 (GND), VR1.3 (A1), VR1.5 (A0), VR1.6 (WLAT), VR1.7 (NC), VR1.9 (DGND), VR1.10 (V-); also elsewhere on the board
GateDriver_OUT: IC3.6 (~OUTPUT_1), IC3.7 (~OUTPUT_2), J24.1
NOT_Converter_Duty: IC3.2 (INPUT), U3.4
unnamed: D3.1 (K), R31.1
unnamed: D4.1 (K), R37.1
unnamed: D6.2 (A), R33.2
unnamed: J9.1, VR1.13 (P0A)
unnamed: J9.2, VR1.12 (P0W)
unnamed: J9.3, VR1.11 (P0B)
unnamed: Q2.2 (B), R14.2
unnamed: C29.1, R30.2, U1.10 (IN+)
unnamed: C29.2, R32.1, U1.9 (IN-)
unnamed: C28.1, R17.2, U2.10 (IN+)
unnamed: C28.2, R23.1, U2.9 (IN-)
RECTIFIER_VBUS: J13.2, U2.8 (VBUS)
Rectifier_IN+: J5.1, J5.2, R17.1, R38.1
Rectifier_IN-: J14.1, J14.2, R23.2, R38.2
RelayIN_Signal: J24.2, Q2.3 (C), R13.2
SCL: VR1.2 (SCL); also elsewhere on the board
SDA: VR1.4 (SDA); also elsewhere on the board
SELECT_CONVERTER: R33.1, SW4.5 (B); also elsewhere on the board
Switch_Relay: R14.1; also elsewhere on the board

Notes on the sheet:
Latch button so we can control whether the hand made or module converter will be used.
Load SHUNT, In our case battery
3.3V
Vin Power Monitor
RectifierIN-
Current Sense Amplifiers with Kelvin Connection
External Supply 10-36V
Load Submodule
Level Shifter Circuit
RectifierIN+
These INA229 design were based from TI and Adafruit EVM's
P0A
P0W
Vout Power Monitor
RelayIN_Signal for Dump Load
Digital Pot for Converter Module
This gate driver has an inverted output, we could invert the PWM signal directly from the uC but I(Hiram) chose to use a spare inverter from the SN74HC14 instead, the drawback is that there is a tiny loss because propagation delays but I think it is a worth price for not dealing with inverted duty 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
ConverterIN_Shunt
Gate Driver Circuit for HandMade Converter
https://a.co/d/08Djs6OC
Gate Driver Out
P0B

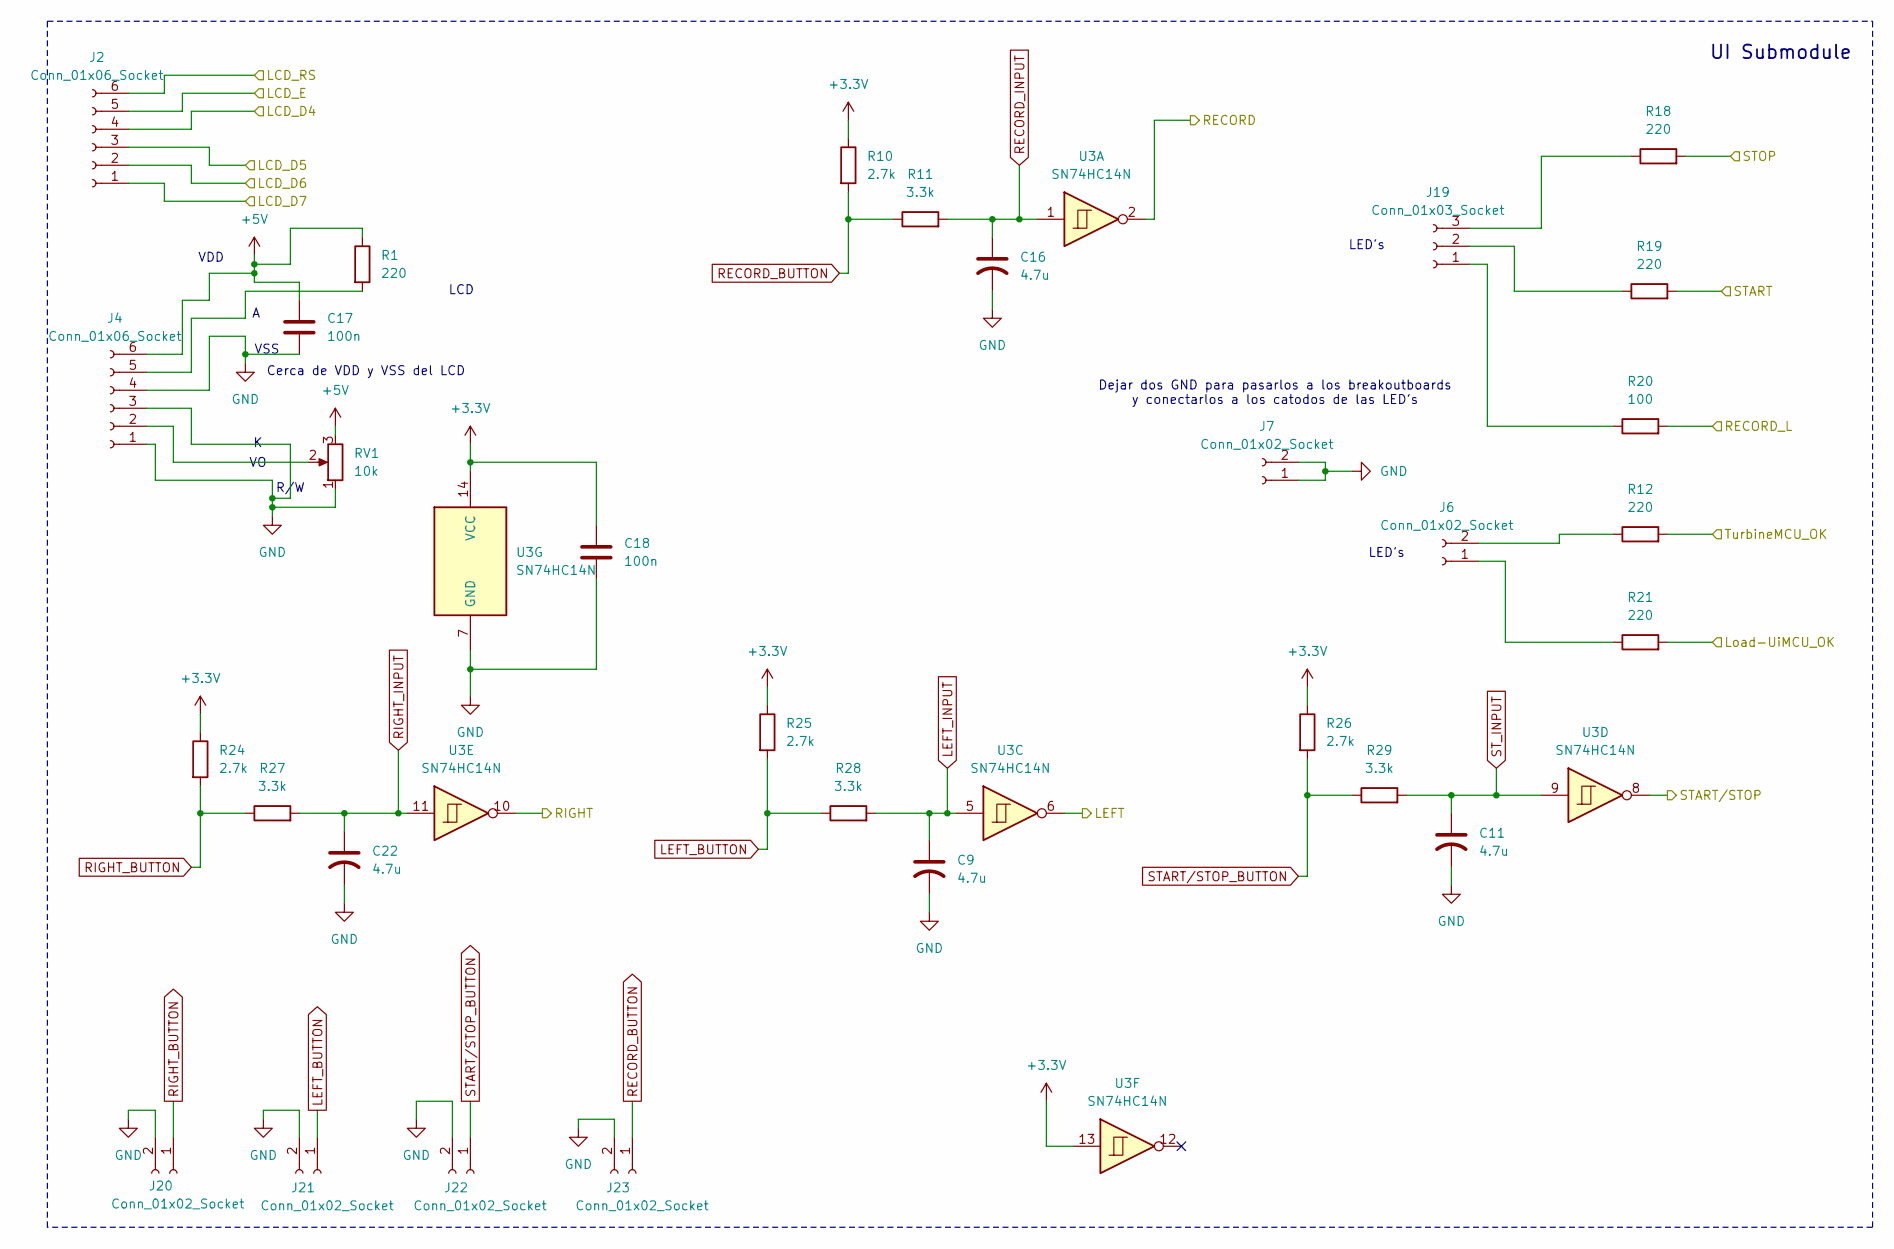
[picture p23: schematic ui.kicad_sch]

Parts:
C9, C11, C16, C22: 4.7u; C_1206_3216Metric_Pad1.33x1.80mm_HandSolder
C17, C18: 100n; C_0805_2012Metric_Pad1.18x1.45mm_HandSolder
J2, J4: Conn_01x06_Socket; JST_XH_B6B-XH-A_1x06_P2.50mm_Vertical
J6, J20, J21, J22, J23: Conn_01x02_Socket; JST_XH_B2B-XH-A_1x02_P2.50mm_Vertical
J7: Conn_01x02_Socket; TerminalBlock_Xinya_XY308-2.54-2P_1x02_P2.54mm_Horizontal
J19: Conn_01x03_Socket; JST_XH_B3B-XH-A_1x03_P2.50mm_Vertical
R1, R12, R18, R19, R21: 220; R_Axial_DIN0207_L6.3mm_D2.5mm_P7.62mm_Horizontal
R10, R24, R25, R26: 2.7k; R_0805_2012Metric_Pad1.20x1.40mm_HandSolder
R11, R27, R28, R29: 3.3k; R_0805_2012Metric_Pad1.20x1.40mm_HandSolder
R20: 100; R_Axial_DIN0207_L6.3mm_D2.5mm_P7.62mm_Horizontal
RV1: 10k; Potentiometer_Bourns_3296W_Vertical
U3: SN74HC14N; CERDIP-14_W7.62mm_SideBrazed

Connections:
+3.3V: C18.1, R10.1, R24.1, R25.1, R26.1, U3.13, U3.14 (VCC); also elsewhere on the board
+5V: C17.1, J4.6, R1.1, RV1.3; also elsewhere on the board
GND: C9.2, C11.2, C16.2, C17.2, C18.2, C22.2, J4.1, J4.3, J4.4, J7.1, J7.2, J20.2, J21.2, J22.2, J23.2, RV1.1, U3.7 (GND); also elsewhere on the board
LCD_D4: J2.4; also elsewhere on the board
LCD_D5: J2.3; also elsewhere on the board
LCD_D6: J2.2; also elsewhere on the board
LCD_D7: J2.1; also elsewhere on the board
LCD_E: J2.5; also elsewhere on the board
LCD_RS: J2.6; also elsewhere on the board
LEFT: U3.6; also elsewhere on the board
LEFT_BUTTON: J21.1, R25.2, R28.1
LEFT_INPUT: C9.1, R28.2, U3.5
LoaduiMCU_OK: R21.2; also elsewhere on the board
unnamed: J4.2, RV1.2
unnamed: J4.5, R1.2
unnamed: J6.1, R21.1
unnamed: J6.2, R12.1
unnamed: J19.1, R20.1
unnamed: J19.2, R19.1
unnamed: J19.3, R18.1
RECORD: U3.2; also elsewhere on the board
RECORD_BUTTON: J23.1, R10.2, R11.1
RECORD_INPUT: C16.1, R11.2, U3.1
RECORD_LED: R20.2; also elsewhere on the board
RIGHT: U3.10; also elsewhere on the board
RIGHT_BUTTON: J20.1, R24.2, R27.1
RIGHT_INPUT: C22.1, R27.2, U3.11
START: R19.2; also elsewhere on the board
START/STOP: U3.8; also elsewhere on the board
START/STOP_BUTTON: J22.1, R26.2, R29.1
STOP: R18.2; also elsewhere on the board
ST_INPUT: C11.1, R29.2, U3.9
TurbineMCU_OK: R12.2; also elsewhere on the board

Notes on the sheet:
LCD
VSS
Cerca de VDD y VSS del LCD
Dejar dos GND para pasarlos a los breakoutboards y conectarlos a los catodos de las LED's
LED's
UI Submodule
VDD
R/W

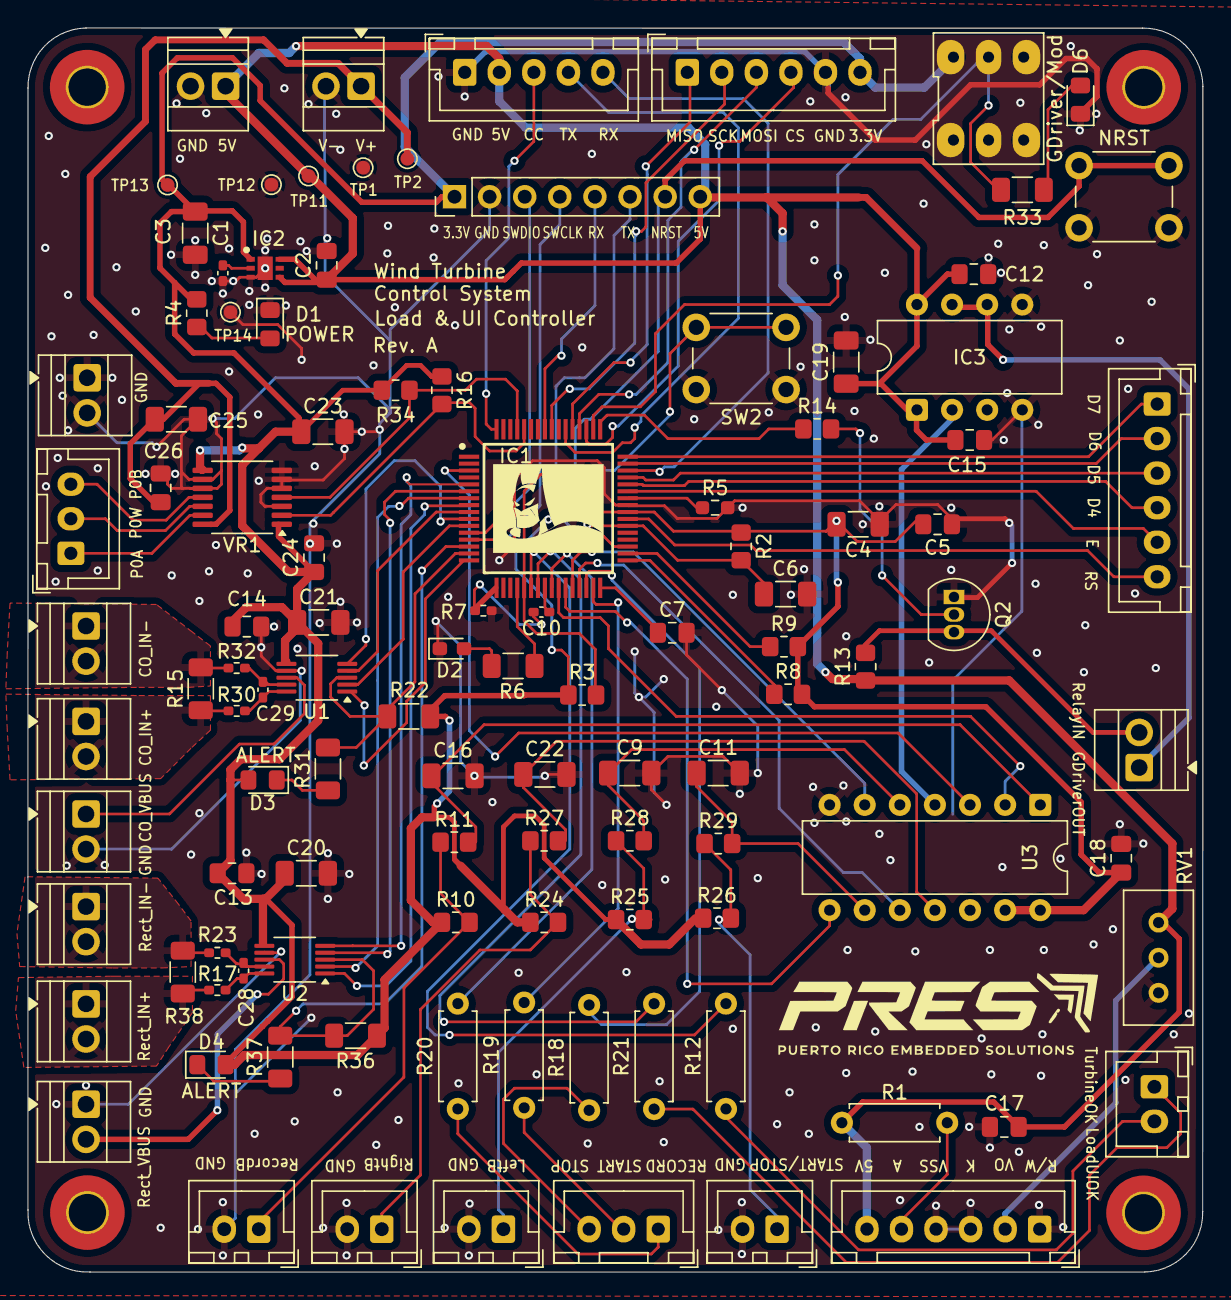
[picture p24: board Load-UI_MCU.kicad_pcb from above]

Board: 4 copper layers, 85.0 x 90.0 mm, 109 parts (0 on the bottom side), 92 nets.

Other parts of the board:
NRST: SW_Push; SW_PUSH_6mm

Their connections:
GND: NRST.2; also elsewhere on the board
NRST: NRST.1; also elsewhere on the board

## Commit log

2026-04-30 Initial KiCad project commit
    [DIL14.stp, DIP794W56P254L946H432Q8N.PcbLib, DIP8.STEP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]
2026-04-30 Updated schematic and cleaned autosave files
    [Load-UI_MCU.kicad_sch]
2026-04-30 Changed NRST button silkscreen
    [Load-UI_MCU.kicad_pcb, Load-UI_MCU.kicad_sch]
2026-04-30 removed unnecessary vias
    [Load-UI_MCU.kicad_pcb]
2026-05-01 Added final changes to PCB: 1. Fixed OV2 ressitors on Power MUX, 2. Added input filtering on both INA229, 3. Changed the LDO layout based on manufacturer recomendations.
    [Load-UI_MCU.kicad_pcb, Load-UI_MCU.kicad_sch, load.kicad_sch]
2026-05-01 Finished pcb for manufacturing, changed some footprints based on what the manufacturer had. Also I fixed the potentiometer footprint.
    [Load-UI_MCU-B_Mask.gbr, Load-UI_MCU-B_Paste.gbr, Load-UI_MCU-B_Silkscreen.gbr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]
2026-05-01 final BOM
    [Load-UI_MCU.csv]
2026-05-04 Removed unnecessary hex inverter, fixed record button connection, change relay resistors to smd
    [Load-UI_MCU.csv, Load-UI_MCU.kicad_pcb, Load-UI_MCU.kicad_sch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]
2026-05-05 Added testpoints
    [Load-UI_MCU.kicad_pcb]
2026-05-05 schematic comments
    [Load-UI_MCU.kicad_sch, load.kicad_sch, ui.kicad_sch]
2026-05-17 Last update after PR4, mostly done I need revisions from rest of members with special attention on grounding layout
    [Load-UI_MCU.kicad_pcb, Load-UI_MCU.kicad_sch, load.kicad_sch]
2026-05-18 added two more testpoints
    [Load-UI_MCU.kicad_pcb, Load-UI_MCU.kicad_sch, load.kicad_sch]
2026-05-19 PCB finished, only final manufacturing files left, BOM, CPL
    [Load-UI_MCU.kicad_pcb, Load-UI_MCU.kicad_sch, load.kicad_sch]
2026-05-20 ready for manufacturing
    [Load-UI_MCU-B_Cu.gbl, Load-UI_MCU-B_Mask.gbs, Load-UI_MCU-B_Paste.gbp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]
2026-05-21 This commit contains all files up dote to Rev A. Load & UI MCU, manufactured on May 21, 2026
    [Load-UI_MCU-B_Cu.gbl, Load-UI_MCU-B_Mask.gbs, Load-UI_MCU-B_Paste.gbp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]
